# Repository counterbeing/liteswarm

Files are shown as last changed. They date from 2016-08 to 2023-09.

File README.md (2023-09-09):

<p align="center">
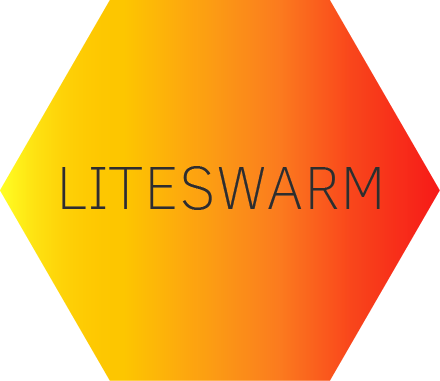
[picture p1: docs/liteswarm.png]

</p>

## 2023-09-08 NOTE
this branch is a merge from a separate repo 100ideas/scarfswarm/releases/tag([BM23](https://github.com/100ideas/scarfswarm/releases/tag/BM23)|[v0.1.0](https://github.com/100ideas/scarfswarm/tree/v0.1.0)) which itself was refactored from [the 2019-july master branch of this  repo counterbeing/liteswarm, somewhere around here](https://github.com/counterbeing/liteswarm/blob/dc4e0e53ea9b77c02f954a00a81d340e21b89678/src/main.cpp). This branch compiles on esp32 dev boards with nrf24 and rotary encoder knobs attached to esp32 GPIO pins as defined in [`/src/config.h`](src/config.h). 

The GPIO pin settings should be compatible with ESP-WROOM-32 DevKit-v1 style breakout boards. I used these "[5PCS ESP-WROOM-32 ESP32 ESP-32S Development Board...](https://www.amazon.com/dp/B0BK13HWBJ) from amazon, but I want to switch to using one of the boards made by [Unexpected Maker](https://unexpectedmaker.com/shop.html) (tbd)."

I forked and old commit of the master branch, back when it was reliably working on arduino teensy in july 2019, and refactored it until it worked on esp32. Note, I have not verified that it STILL works on arduino teensy, so we should add a tag to the old master at a commit that was good on teensy, maybe around here https://github.com/counterbeing/liteswarm/blob/dc4e0e53ea9b77c02f954a00a81d340e21b89678/src/main.cpp. The most recent master commit before my merge from BM23 branch was https://github.com/counterbeing/liteswarm/tree/cc187bc9ed60972e2afc4fb52d72f6577941fd4b.

I started a new repo for my development work, [100ideas/scarfswarm](https://github.com/100ideas/scarfswarm).

## about
continutation of code developed with @counterbeing in https://github.com/counterbeing/liteswarm. `BM23` (and `master` currently) branch here is a minimal refactor of the teensy/arduino-compatible master branch of the liteswarm repo from 2019. Multiple contributors attempted to refactor or rearchitect the liteswarm code for esp32 but I couldn't get any of those branches to run. This branch does run on esp32, but it is not fancy. In fact, the code is ugly. But it works. I will push it to a branch on counterbeing/liteswarm for posterity. This repo is intended to be the home of scarfswarm FOSS firmware and hardware based on esp32, contributed by 100ideas and others.

To compile and upload this code onto an ESP32, use platformio in vscode. Once the platformio extension is activated, it should automagically configure a local gcc toolchain, download the project dependencies (`fastled/FastLED@^3.5.0`, `dparson55/NRFLite@^3.0.3`, `madhephaestus/ESP32Encoder`, `thomasfredericks/Bounce2@^2.55`, and all the magic contained in the `framework = arduino` line of `platformio.ini`), and compile them for esp32. If you encounter trouble building, try disabling `gcc` warnings by using a `platform.ini` similar to below (specifically `build_unflags` line):
```ini
[env:esp32dev]
platform = espressif32
board = esp32dev
framework = espidf
upload_port = /dev/cu.SLAB*
monitor_port = /dev/cu.SLAB_USBtoUART
monitor_speed = 115200
; esp32_exception_decoder is an add-on that parses kernel panic messages on serial such that error codes
;   and memory locations / program counter numbers are replaces with src code coordinates - handy!
monitor_filters = default, esp32_exception_decoder
; fix vendor-default extreme error setting in GCC (example code won't compile)
;   by disabling all gcc warnings
;   https://community.platformio.org/t/disable-warning-errors/13280/3
build_unflags = -Werror=all
; in extreme cases you may need to mess with how the linker/compiler resolves dependencies, try:
; lib_ldf_mode = chain+
```

**END 2023-09-08 NOTE**
---

## Swarming LEDs for LED Fun
This project can be be applied to many projects. Our prototype has been in scarves. These can also go in all sorts of other places:

- Wearables such as scarves and hats.
- Bike safety helmet.
- Bike lights.

### Why these? What's the swarm?
The thing that makes this project unique is the swarm. We're working to establish a way for multiple projects to communicate so that you can sync up animations with friends or even strangers.

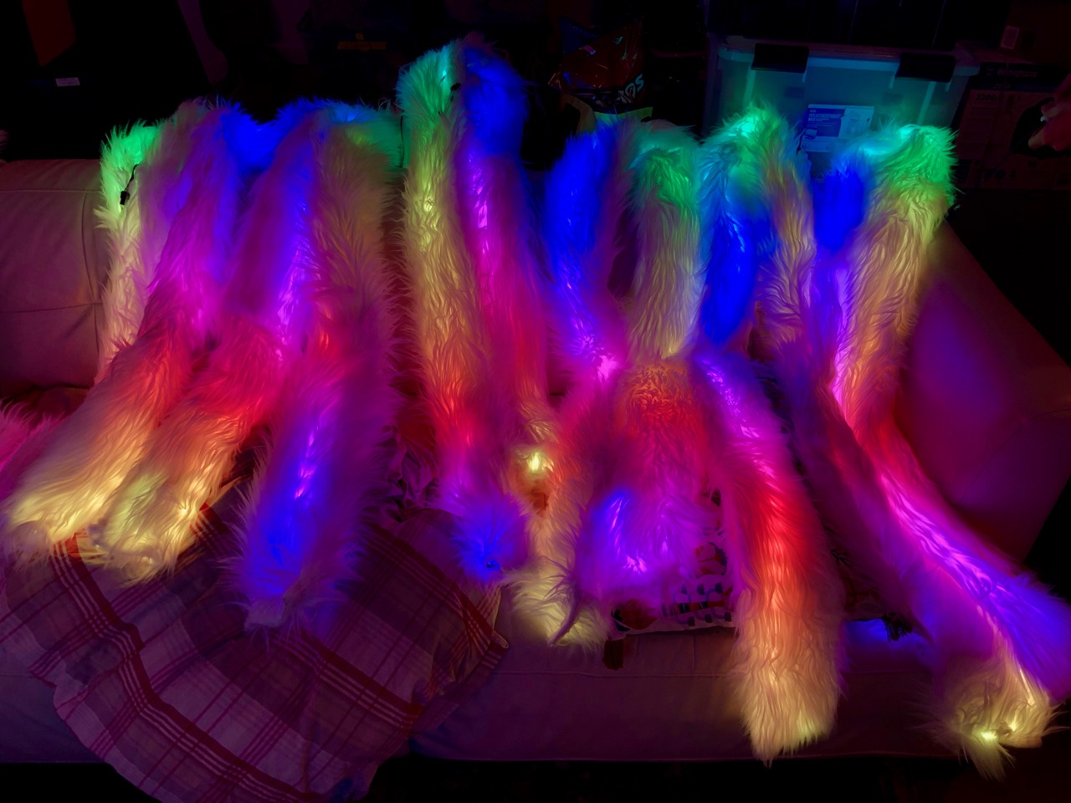
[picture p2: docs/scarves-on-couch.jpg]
Pile of scarves synced up


Cheap simple hardware that can be put together in a robust and ad-hoc way to
keep you safe for nights of partying, or bicycling. Keep your friends all in a group with a synchronized mobile light show.

### Materials / Shopping List
These are some of the materials we've used to build our own. You can pretty much bank on them workin for your project.
- [portable battery packs](https://smile.amazon.com/Smallest-Jackery-3350mAh-Portable-Charger/dp/B00L9F95RO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), not a bad idea to have two. These are small enough to fit inside of a fuzzy scarf, and they don't turn off on you. You can get a few hours out of one of these... Depends on the animation you run. *mac likes Jackery if you can find 6000-12000mAh capacity for less than $20)
- another batt option [PowerAdd Slim 2 5000 mAh Compact Battery Packs](https://www.amazon.com/dp/B00KG45W08) ($13)
- [fabric](https://www.joann.com/luxury-faux-husky-fur-fabric--white/14387674.html)
- [arduino nanos](https://smile.amazon.com/gp/product/B07HF5RMHV/ref=crt_ewc_title_dp_2?ie=UTF8&psc=1&smid=A278BT9THV444Y)
- [led strips](https://www.aliexpress.com/item/5m-5V-WS2812B-WS2812-Led-Strip-light-Individually-Addressable-Smart-RGB-Led-pixel-strips-Black-White/32995915537.html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)
- moar strips [WS2811](https://hackmd.io/@100ideas/scarfswarm#LED-strips) (see hackmd doc below for links to Ray Wu's led store)
- [usb cables](https://www.amazon.com/HTTX-Straight-Soldering-Connector-Replacement/dp/B07D1HDJM8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)
- [rotary encoder](https://smile.amazon.com/DIYhz-Rotary-Encoder-Digital-Potentiometer/dp/B07D3D64X7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)
- [wire](https://www.amazon.com/StrivedayTM-Flexible-Silicone-electronic-electrics/dp/B01KQ2JNLI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)
- [nRF24L01+ 2.4 Ghz radio](http://a.co/d/3rhLgCT)
- Bourns PEC11 12mm 24-pulse rotary encoder (PEC11-4215F-S24) [adafruit #377](https://www.adafruit.com/product/377) ($4.50/1); [datasheet](https://cdn-shop.adafruit.com/datasheets/pec11.pdf) (need 10x)
- [usb type a male adapter 20-pack]( https://www.amazon.com/gp/product/B07GGJGB7Q) ($11) (for making power cables)
- [JST 4pin male-female connector pigtails, pack of 20](https://www.amazon.com/gp/product/B075K3M1TB) ($11)
- [112Pcs 2.54mm Male and Female Pin Header Connector Assortment Kit, 100pcs Stackable Shield Header](https://www.amazon.com/gp/product/B07CWSXY7P) ($13)
- [Capri Tools 20011 Automatic Wire Stripper and Cutter
](https://www.amazon.com/gp/product/B01018CX46) ($14) - get one. changed my life.

scarfwarm-bigred-demo[
Scarfswarm / bikelights Big Red animation demo (youtube 2m)](https://youtu.be/5sAtdrZpyJc)

## Contributing
### Getting Involved
If you'd like to submit a bug, go ahead and use the issue tracker.

If you'd like to make submit a feature or a fix.
  - Open an issue to get buy in.
  - Fork the repo.
  - Make your changes.
  - Submit a pull request.

### Troubleshooting
Things you might be missing.
- edit using VSCode with PlatformIO plugin
- OpenOCD some USB stuff `brew install openocd` (or else `dyld: Library not loaded: /usr/local/opt/libftdi/lib/libftdi1.2.dylib`)

## Reference
**project documentation** https://hackmd.io/@100ideas/scarfswarm

libraries we're using:
- [FastLED.h](https://github.com/FastLED/FastLED) let their be light
- [NRFLite.h](https://github.com/dparson55/NRFLite) ... longwave light
- arduino / teensy [SPI](https://www.pjrc.com/teensy/td_libs_SPI.html) library
- [Encoder](https://github.com/PaulStoffregen/Encoder) - performant quadrature encoder for rotary inputs
- 

---

## 2019-12-12 Teensy-LC + NRF24L01+ notes

teensy forum faq: https://forum.pjrc.com/threads/25395-Teensy-Quick-Reference-Code-Examples-Tips-and-Tricks?highlight=nrf24l01
- also see
  - getting 128-bit ID hardcoded into chip
  - interval timer using interrupts
  - simple task library
  - libs https://www.pjrc.com/teensy/td_libs.html
    - debounce
    - timers

Optimized High Speed NRF24L01+
- https://tmrh20.github.io/RF24/
- mentioned on pjrc forums https://forum.pjrc.com/threads/40499-Need-to-change-SPI-clock-rate-for-RF24-radio-modules-w-TMRh20-library

NRF24L01+ w/ amazon breakout boad diagram
-----------------------------------------------------------------------------------------------

                                                 (pins)       NRF24L01+ breakout board pcb
    | nrf:teensy pin# | nrf:teensy     |      |-----------------------------------------------|
    | --------------- | -------------- |      |[1] | 2  |                      (antenna)      |
    | 1: GND   GND    | 2: VCC  (+3.3v)|      | -- | -- |        -------     ===============  |
    | 3: 9     CE     | 4: 10?  CSN    |      | 3  | 4  |        | C H |        ||   -----||  |
    | 5: 13    SCK    | 6: 11   MOSI   |      | -- | -- |        | I P |        ||   ||-----  |
    | 7: 12    MISO   | 8: ?    IRQ    |      | 5  | 6  |        -------        ||   -----||  |
                                              | -- | -- |                       ||   ||-----  |
                                              | 7  | 8  |                       ||   -----||  |
    Functions as follows:                     |---------|                            ||-----  |
    1: Ground                                 |         ( 16.000 )                        ||  |
    2: Vcc (3.3v)                             |-----------------------------------------------|
    3: CE (Chip Enable)
    4: CSN (Chip Select Not) Active Low - SPI Chip Select function
    5: SCLK (Clock) - SPI Clock Function
    6: MOSI (Master Out Slave In) - SPI Data
    7: MISO (Master In Slave Out) - SPI Data
    8: IRQ (Interrupt) - Optional, but goes low to indicate that data has arrived, fault has
       occurred, or write buffer full.

> SPI has 4 signals: **SS**, **SCK**, **MOSI**, **MISO**. SCK is a clock signal. Master Out Slave In (MOSI) sends data from the SPI master to one or more slaves. Master In Slave Out (MISO) is how slaves send data back to the master. To talk to only one of several slaves, the Slave Select (SS) pin is used. Thus, some chips need only 3 or even 2 of these signals; a display, for example, will use MOSI but not MISO, as it is an output only device.
>
> Multiple SPI devices use the same SPI SCK, MISO and MOSI signals but each device will need it's own SS pin.

| Signal | Function | Teensy 2.0 | Teensy++ 2.0 | Teensy 3+ / LC * | ALT Teensy 3+ / LC |
| --- | --- | --- | --- | --- | --- |
| SS | Select device | 0 | 20 | 10 | - |
| SCK | Clock | 1 | 21 | 13 | 14 |
| MOSI | Data Output | 2 | 22 | 11 | 7 |
| MISO | Data Input | 3 | 23 | 12 | 8 |

\* these pins are set by default by SPI library(?). To use ALT, make calls to `SPI.setMOSI(pin)` etc.

> However, the SS pin must either be configured as an output, or if it is an input, it must remain low during the SPI transfer. Unconfigured pins default to input, and a pin with no signal can easily "float" to random voltages due to electrical noise. Always configure the SS pin as an output, or make sure it remains low.
>
> Sometimes, the SPI pins are already in use for other tasks when an SPI device is added to a project. If that task is simply a digital pin, or an analog input, it is usually better to move that to another pin so that the hardware SPI can be used. Sometimes though, the conflicting pin cannot be moved. The Audio Adapter, for example, uses some of the SPI pins to talk to the Audio DAC over I2S. For this case, Teensy 3.x provides an alternate set of SPI pins.
>
> The main SPI pins are enabled by default. SPI pins can be moved to their alternate position with SPI.setMOSI(pin), SPI.setMISO(pin), and SPI.setSCK(pin). You can move all of them, or just the ones that conflict, as you prefer. The pin must be the actual alternate pin supported by the hardware, see the table above; you can't just assign any random pin.

https://www.pjrc.com/teensy/td_libs_SPI.html

-----------------------------------------------------------------------------------------

## dont overflow if counting packets...
how many packets (max) could a device see per second?
```
(800kbps * 1 second) / 32 bytes = 3125
(2MBps * 1 second) / 32 bytes   = 62500
```
see UINT_MAX from std::numeric_limits 
- https://en.cppreference.com/w/cpp/types/climits
- https://en.cppreference.com/w/cpp/types/integer

| uint sizes | atmel / arduino | teensylc arm cortex M0 |
| --- | --- | --- |
| INT8_MAX | 127 | |
| UINT8_MAX  | 255 | |
| INT16_MAX  | 32767 | |
| UINT16_MAX | 65535 | |
| INT32_MAX  | 2147483647 | |

```c
// https://www.badprog.com/c-type-what-are-uint8-t-uint16-t-uint32-t-and-uint64-t

// testValue
unsigned long long testValue     = 0xFFFFFFFFFFFFFFFF; // 18446744073709551615

// 1 byte -> [0-255] or [0x00-0xFF]
uint8_t         number8     = testValue; // 255
unsigned char    numberChar    = testValue; // 255

// 2 bytes -> [0-65535] or [0x0000-0xFFFF]
uint16_t         number16     = testValue; // 65535
unsigned short    numberShort    = testValue; // 65535

// 4 bytes -> [0-4294967295] or [0x00000000-0xFFFFFFFF]
uint32_t         number32     = testValue; // 4294967295
unsigned int     numberInt    = testValue; // 4294967295

 // 8 bytes -> [0-18446744073709551615] or [0x0000000000000000-0xFFFFFFFFFFFFFFFF]
uint64_t             number64         = testValue; // 18446744073709551615
unsigned long long     numberLongLong    = testValue; // 18446744073709551615
```

## deviceId collisions
calculate liklihook of id collisions, where n = number of devices & d = keyspace size (using birthday problem formula):

1 - (d!) / ((d - n)! * d^n)

n = 10 devices
d = 256 (uint_8)
p = 16%

n = 10 devices
d = 32768 (uint_16)

### 2019-11-21 dev notes for scarfquest
intellisense not picking up uintxx types from `/Users/100ideas/.platformio/packages/toolchain-atmelavr/avr/include/stdint.h`

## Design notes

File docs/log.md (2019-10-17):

## LOG

#### 22 aug 19
- got WS2815s working
- discovered that `NUMLEDS = 375` uses 120% of available memory
  - removing all serial.print statements with static strings saved 406 bytes
  - that was enough space for all animations @ 375 leds
- measured current draw for WS2815 for each animation @ 375 leds (12.5 m)
  - ranges between 0.8-4.25 amps @ 12v
  - so for 25m of strip on big red max power draw ~ 100 watts
  - see comments in `config.h` for details

#### 14 aug 19
- set `"C_Cpp.clang_format_style": "Google",` in `.vscode/settings.json` to get javascriptish formatting rules
- added `include/printf.h`: if included, intercepts output of printf and sends to `serial.print()`. not currently used, but should be.

#### 13 aug 19
- switch push-pattern cmd dispatcher
- FIX pcb v1.3 swapped CS<->CSM pins in `Radio.h`
  ```c
    const static uint8_t PIN_RADIO_CE = 7;  // 7 on PCBs 1.3, was 6 on 1.1
    const static uint8_t PIN_RADIO_CSN = 6; // 6 on PCBs 1.3, was 7 on 1.1
  ```
- determined color channel order for SK9822: BGR

- c experiments
  - https://repl.it/@100ideas/hashmap-vs-switch
  - https://repl.it/@100ideas/knobreducer-binary-sandbox
  - https://repl.it/@100ideas/c-string-and-array-practice
  - https://www.programiz.com/cpp-programming/strings
  - https://en.cppreference.com/w/cpp/language/operator_arithmetic

- buffer rapid presses TODO pseudocode
  ```
  // TODO buffer rapid presses
    } else { ....
      IF rapid presses (where difference < shortPress):
        skip (*_aiIndex)++;
        instead increment rapidPressCount++, once per rapid press
      IF rapid presses over (buttonState == 1 && rapidPressCount > 0)
        (*_aiIndex) += rapidPressCount;
        rapidPressCount == 0;
  ```

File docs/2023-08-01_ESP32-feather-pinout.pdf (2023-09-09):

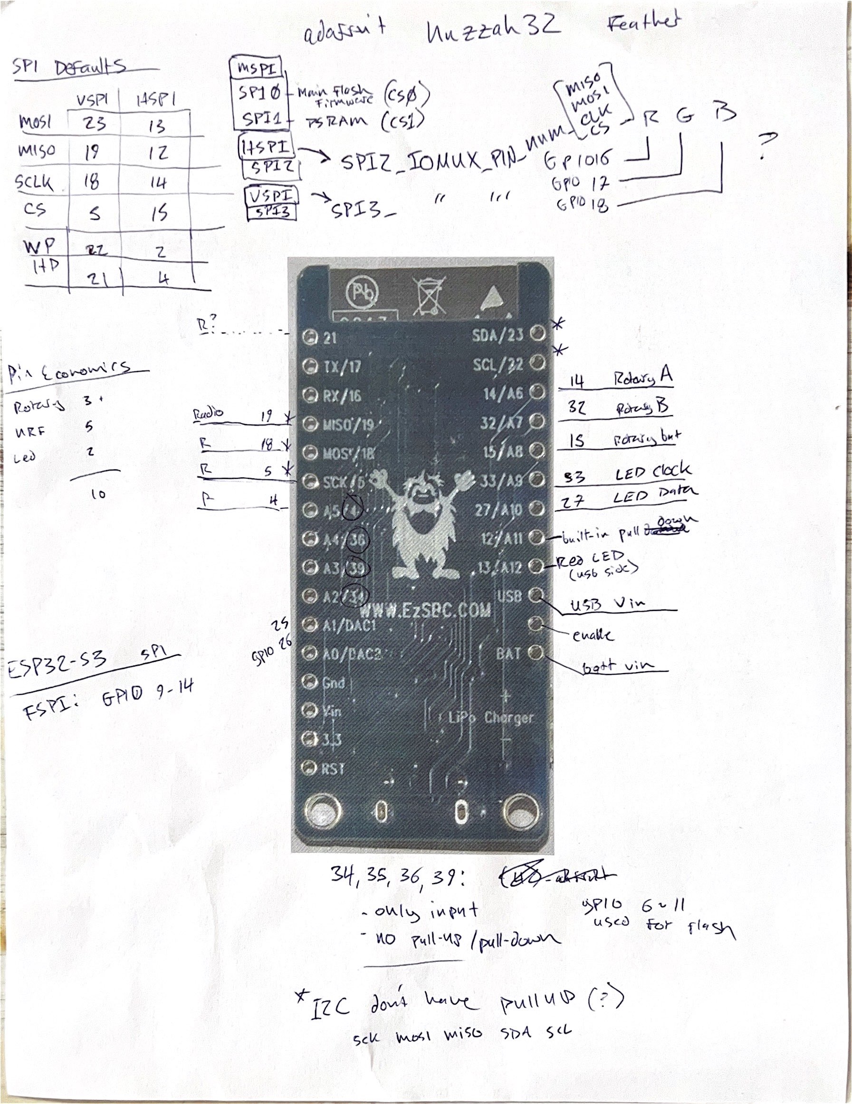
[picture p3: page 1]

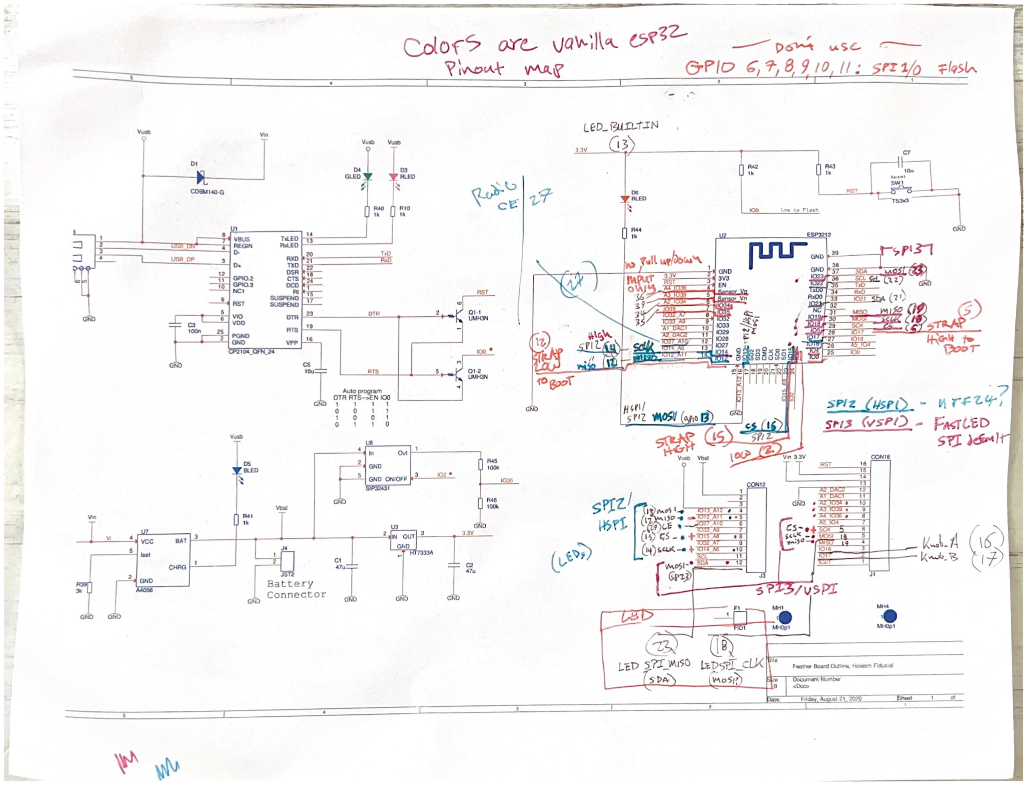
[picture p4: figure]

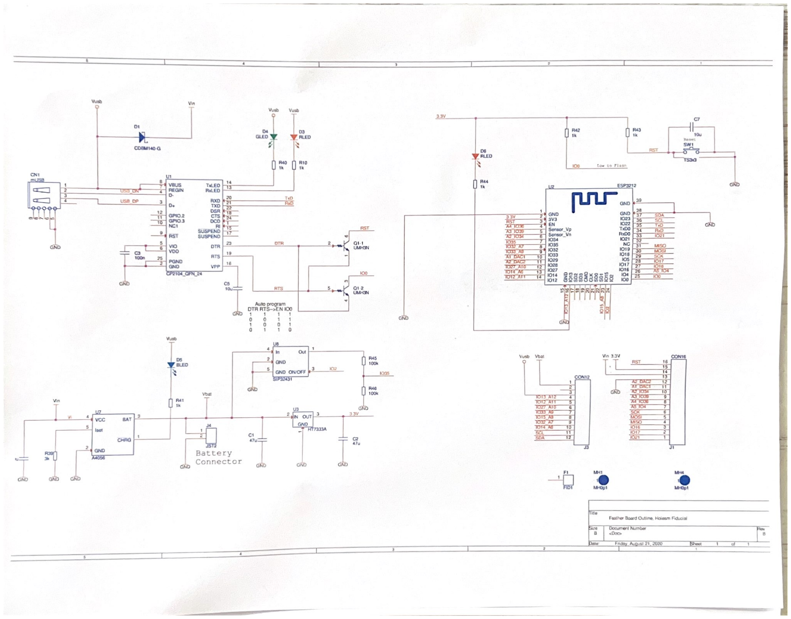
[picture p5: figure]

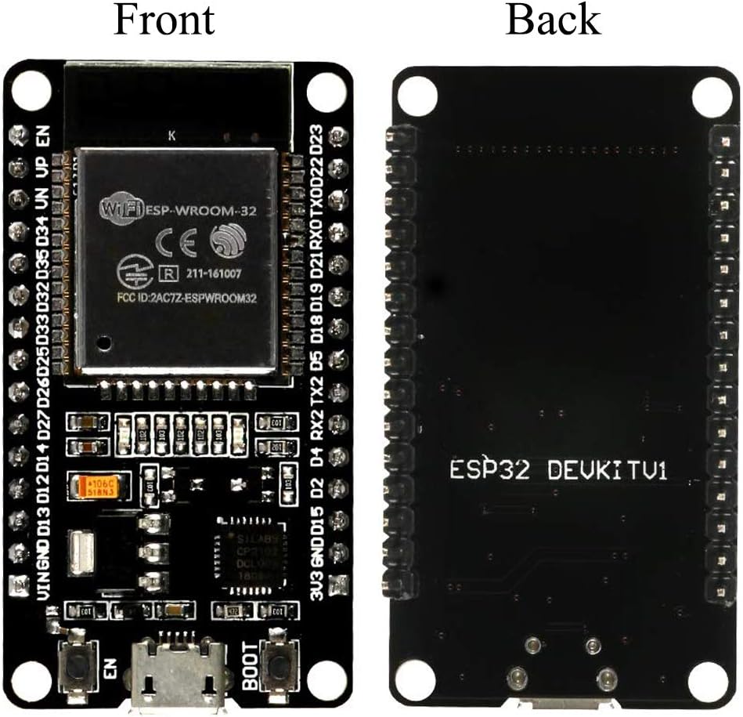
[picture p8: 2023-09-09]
docs/2023-08-01_esp32-devkitv1-amazon_dp_B0BK13HWBJ copy.jpg

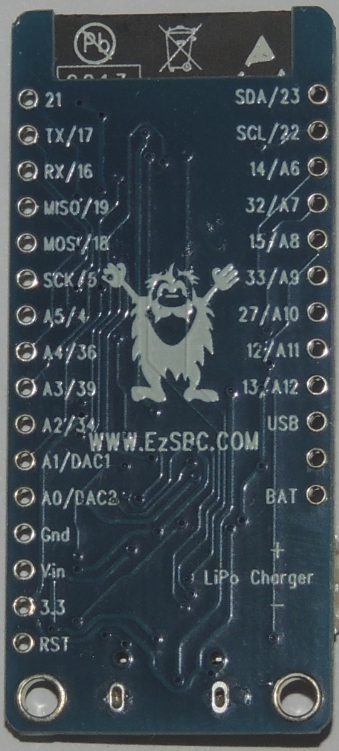
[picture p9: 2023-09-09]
docs/2023-08-01 product_e_s_esp32_feather_back.jpg

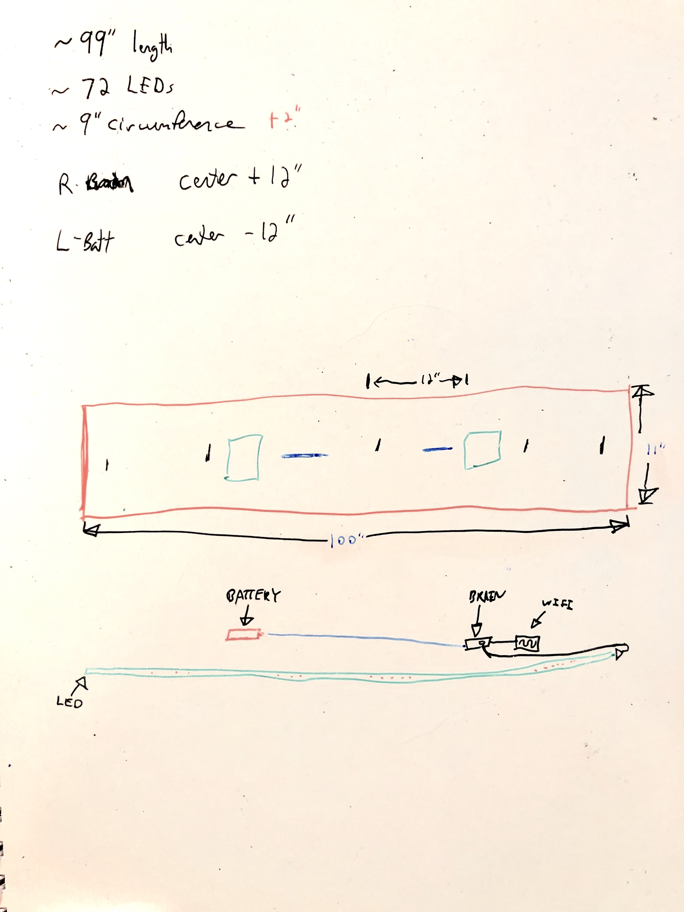
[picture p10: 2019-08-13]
scarf-diagram.jpg

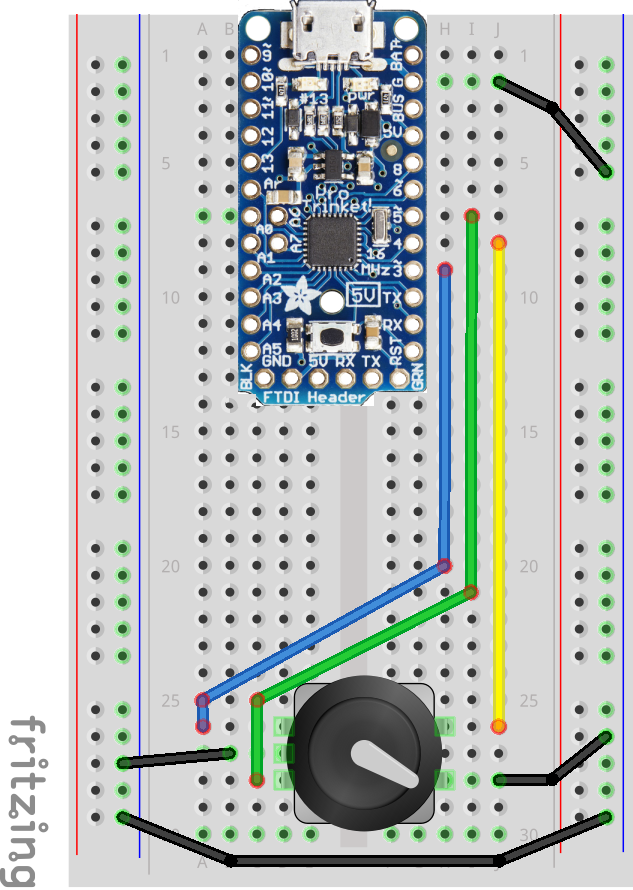
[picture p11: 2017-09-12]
docs/rotary encoder - pro-tinket_Volume_Knob_Fritzing.png

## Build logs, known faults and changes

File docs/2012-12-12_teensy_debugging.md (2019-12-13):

# 2012-12-12 teensy dev & debugging

working on refactoring code from the 'master' branch for teensy_lc.

Hardest part was figuring out the correct pinouts for the radio. 
- `neopixel` style LED strip worked right off the bat
- so did rotary encoder
- radio is hard b/c nrf docs use terms like `csn`, & `ce`, but teensy uses `ss` and doesn't mention the other term as much. See the section in the `readme.md` for an overview.

problem initially presented itself as nrf radio module + NrfLite lib on teensy reporting via terminal that 1) `radio ok`  but 2) logged values for received packets that never changed. As if the packets weren't really getting decoded (although they were being received somehow).

Three theories:

1). wiring is screwed up connecting teensy to nrf, so it isn't able to fully read or correctly decode incoming packets.

2). there is a buffer overflow, typecasting/type mixing mistake in the code. the nrf is working, receiving packets, but decoding them is not; instead we get nonsense or zeor values from random memory locations. I was leaning towards this explanation because I found a ton of mixed types (uint8_t -> int; long -> int, etc). But after standardizing a bunch of them, still got communication problems.

3). the teensy has a much faster clock (100mhz?) than the arduino. According to the official documentation and forum/issue posts on nrflite repo, the crystal resonator in the nrf24l01 that generates the radio frequencies is unable to work effectively above some frequency range... perhaps 8khz at the high end? [Here is an issue on nrflite recommending limiting clock speed to 4khz](https://github.com/dparson55/NRFLite/issues/19). But based on reading the issue, it doesn't sound particularly straightforward to force the arduino + nrf libs running on the teensy to step down to 4khz. Gonna play with this next. [also a forum post on teensy forums](https://forum.pjrc.com/threads/40499-Need-to-change-SPI-clock-rate-for-RF24-radio-modules-w-TMRh20-library).

4). well one last theory: I skimmed the commit log for the master branch (counterbeing/bikelights) and didn't see anything too alarming, so thats what I adapted. But its totally possible it has subtle work-in-progress bits that are tripping up the logic of the current program. I've gone over everything a multiple times but nothing is obviously screwed up... could you guys have a look?

### changes on this branch
- added more preporcessor / compiler directives to config.h to simplofy switching between developing for nano vs teensy
- added teensy config to `platformio.ini`. this should make two `"env"` (board)-dependant sections appear in the platformio "project tasks" sidebar, one for nano, and one for teensy. Just plug whichever board in and click the appropriate build/compile/monitor - it figures it out on its own.
- standardized data types used to pack & upack the radio packet.

### symptoms
see console log below. its the serial output of a nano running on my desk right next to the teensy. its getting the correct 'shared_secret', and 'animationId' increments on the receiver if I spem the rotary over and over, but the system almost immediately races away from user input towards some minima or maxima; in particular, neither unit successfully synchronizes towards shared state with the other one, at least with the 'rotaryPosition' parameter. The other params seem to be more stable.

So I think whats happening is a bad logic around [line 90 of Radio.h](https://). The `stateChanged()` method always sees a different local rotaryPosition than the one in the incoming packet, so it spams updates at the other device, the recipient spams back, and both get locked in an unstable positive feedback loop.  (*note: maybe we should add a naieve 'back-off' algorithm to the radios to keep the packet density from spiraling out of control like this - that, and adding CRC / checksum code...)

**anyway, I can't figure out why currentRotary** isn't getting set correctly from the incoming packets. Am I trying to compare the literal value of the pointer to the local currentRotary with the proper value of the incoming packet (fail), or is the memory space of the struct in which the packet is stored is getting overriden (yes? can't tell), or is it unintended behavior from the interplay of code that sets the `rotaryPosition` after it changes (due to incoming packet or user input) and the code the animations call (` `MyKnob.h` line 442: confine()`) to scale and loop the rotary values over a particular range?

Well, I've tried a bunch of little experiments and came up with nada. I finished 2/3rds of the pcb of the teensy yesterday and I need to finish it and submit it soon to have a chance at getting it fabbed for xmas. I would love to have fully validated the software side before comitting to particular pins on the teensy but I'm stuck - can you help?  Tell me if I'm using an out of date branch (gaaaahhh), or perhaps you'll see the data type error if there is one, or merge my config.h changes into your/Tony's remastered branch.

---

see how `rotaryPosition` changes (or doesn't) in response to me playing with the knob on either the teensy (remote) or nano (logged to serial).

some interesting values:

`rotaryPosition`:

| incoming value | local value |
| --- | --- |
| `-939524096` | `5` |
| `0` | `5` |
| ...later | ... |
| '0' | '255' |

- senderId sometimes shows the correct value
- shared secret was `0` for a long time. not sure how I fixed it.

## control test
testing this codebase with two vanilla nano scarves, both neopixel

#### test 1: 
- nano_a has code from this branch (teensy) with latest commit
- nano_b has whatever code I put on it over thanksgiving. (it was working then).
-  rotary on nano_b 
  - clicking: nano_b flashes quickly - probably switching to new animation then instantly switching back. won't stay switched. similar to teensy.
  - twisting - unsure if this does anything
  - nothing shows up in serial
  - nothing appears to happen to nano_a
-  rotary on nano_a:
  - clicking: switched to next animation for approx 1 sec, then back. no effect on nano_a. fast clicking can advance through several animations
  - twisting: seems to modulate animation as expected

#### test 2: 
- nano_a & nano_b have code from this branch (teensy) with latest commit
- **AW FUCK** both scarves perform more or less as expected. no crazy values, no runaway feedback loops....
- **so its probably not code... but bad wiring or the clock rate on the teensy**.

## new theory: compiler pads memory space of packet struct differently on nano (8-bit) vs teensy (32-bit)

I think this is what's going on! will test soon.

apparently the c compiler tries optimize the memory layout of *struct*ure members according to constraints / rules that partially depend on system architecture (word size?). If the struct's members are of different sizes, the compiler may elect to pad the smaller ones such that the whole struct lays out more regularly in memory.

Our code currently packs 4 numbers into a 48-byte `struct` that is passed to the radio for transmission, or conversely received and unpacked.

The preferred memory layout of the stuct in memory space is probably different on teensy vs nano - thus leading to what appear to be buffer overrun type bugs when one platform gets a packet with that was packed and padded for a different architecture.

apparently the `#pragma pack(n)` compiler directive can control the compilers packing strategy, where n = how many padding bytes can be added around each member to make the struct's overall memory footprint "square". `n = 1` should make it nice and "1-dimensional" and resolve the problem if we're lucky (hopefully its not more complicated than this).

**thanks be to @SadatD for the following explaination, originally posted to https://stackoverflow.com/questions/3318410/pragma-pack-effect#3318475**: 

>  `#pragma pack` instructs the compiler to pack structure members with particular alignment.  >  Most compilers, when you declare a struct, will insert padding between members to ensure that they are aligned to appropriate addresses in memory (usually a multiple of the type's size).  This avoids the performance penalty (or outright error) on some architectures associated with accessing variables that are not aligned properly.  For example, given 4-byte integers and the following struct:
>
>      struct Test
>      {
>         char AA;
>         int BB;
>         char CC;
>      };
>  
>  The compiler could choose to lay the struct out in memory like this:
>  
>      |   1   |   2   |   3   |   4   |  
>  
>      | AA(1) | pad.................. |
>      | BB(1) | BB(2) | BB(3) | BB(4) | 
>      | CC(1) | pad.................. |
>  
>  and `sizeof(Test)` would be 4 &times; 3 = 12, even though it only contains 6 bytes of data.  >  The most common use case for the `#pragma` (to my knowledge) is when working with hardware devices where you need to ensure that the compiler does not insert padding into the data and each member follows the previous one.  With `#pragma pack(1)`, the struct above would be laid out like this:
>
>      |   1   |
>  
>      | AA(1) |
>      | BB(1) |
>      | BB(2) |
>      | BB(3) |
>      | BB(4) |
>      | CC(1) |
>  
>  
>  
>  And `sizeof(Test)` would be 1 &times; 6 = 6.
>  
>  With `#pragma pack(2)`, the struct above would be laid out like this:
>  
>      |   1   |   2   | 
>  
>      | AA(1) | pad.. |
>      | BB(1) | BB(2) |
>      | BB(3) | BB(4) |
>      | CC(1) | pad.. |
>  
>  And `sizeof(Test)` would be 2 &times; 4 =  8.
>  
>  Order of variables in struct is also important. With variables ordered like following:
>  
>      struct Test
>      {
>         char AA;
>         char CC;
>         int BB;
>      };
>  
>  and with `#pragma pack(2)`, the struct would be laid out like this:
>  
>  
>      |   1   |   2   | 
>  
>      | AA(1) | CC(1) |
>      | BB(1) | BB(2) |
>      | BB(3) | BB(4) |
>  
>  and `sizeOf(Test)` would be 3 × 2 = 6.
>   .

references:
- https://forum.pjrc.com/threads/24940-Teensy-3-1-nrf24l01-issue
- https://docs.microsoft.com/en-us/cpp/preprocessor/pack?view=vs-2019

can't wait

---

### nano communicating with teensy v2 (teensy branch latest)
``` log
> Executing task: platformio run --target upload --target monitor --environment nano <

Processing nano (platform: atmelavr; board: nanoatmega328new; framework: arduino)
--------------------------------------------------------------------------------------------------
Verbose mode can be enabled via `-v, --verbose` option
CONFIGURATION: https://docs.platformio.org/page/boards/atmelavr/nanoatmega328new.html
PLATFORM: Atmel AVR 2.0.0 > Arduino Nano ATmega328 (New Bootloader)
HARDWARE: ATMEGA328P 16MHz, 2KB RAM, 30KB Flash
PACKAGES: toolchain-atmelavr 1.50400.190710 (5.4.0), framework-arduino-avr 5.0.0, tool-avrdude 1.60300.190628 (6.3.0)
LDF: Library Dependency Finder -> http://bit.ly/configure-pio-ldf
LDF Modes: Finder ~ chain, Compatibility ~ soft
Found 11 compatible libraries
Scanning dependencies...
Dependency Graph
|-- <FastLED> 3.3.2
|   |-- <SPI> 1.0
|   |-- <SoftwareSerial> 1.0
|-- <Bounce2> 2.52
|-- <Encoder> #4c4ec3a
|-- <SPI> 1.0
|-- <NRFLite> 2.2.2
|   |-- <SPI> 1.0
Building in release mode
Checking size .pio/build/nano/firmware.elf
Advanced Memory Usage is available via "PlatformIO Home > Project Inspect"
DATA:    [=======   ]  68.9% (used 1412 bytes from 2048 bytes)
PROGRAM: [=====     ]  46.6% (used 14306 bytes from 30720 bytes)
Configuring upload protocol...
AVAILABLE: arduino
CURRENT: upload_protocol = arduino
Looking for upload port...
Auto-detected: /dev/cu.usbserial-1460
Uploading .pio/build/nano/firmware.hex

avrdude: AVR device initialized and ready to accept instructions

Reading | ################################################## | 100% 0.00s

avrdude: Device signature = 0x1e950f (probably m328p)
avrdude: reading input file ".pio/build/nano/firmware.hex"
avrdude: writing flash (14306 bytes):

Writing | ################################################## | 100% 2.51s

avrdude: 14306 bytes of flash written
avrdude: verifying flash memory against .pio/build/nano/firmware.hex:
avrdude: load data flash data from input file .pio/build/nano/firmware.hex:
avrdude: input file .pio/build/nano/firmware.hex contains 14306 bytes
avrdude: reading on-chip flash data:

Reading | ################################################## | 100% 1.87s

avrdude: verifying ...
avrdude: 14306 bytes of flash verified

avrdude: safemode: Fuses OK (E:00, H:00, L:00)

avrdude done.  Thank you.

================================== [SUCCESS] Took 6.97 seconds ==================================
--- Miniterm on /dev/cu.usbserial-1460  115200,8,N,1 ---
--- Quit: Ctrl+C | Menu: Ctrl+T | Help: Ctrl+T followed by Ctrl+H ---
0Picking random radio id: 17831
------CE & CSN---------
PIN_RADIO_CE (chip enable): 7
PIN_RADIO_CSN (chip select / slave select)?: 6
radio ok
------INCOMING---------
SHARED_SECRET: 42
rotaryPosition: -939524096
         (local rotaryPosition: 40)
animationId: 0  (local animationId: 0)
senderId: 0
------INCOMING---------
SHARED_SECRET: 42
rotaryPosition: -939524096
         (local rotaryPosition: 5)
animationId: 0  (local animationId: 0)
senderId: 0
--- Sending Data
------INCOMING---------
SHARED_SECRET: 42
rotaryPosition: 0
         (local rotaryPosition: 5)
animationId: 0  (local animationId: 0)
senderId: 0
--- Sending Data
------INCOMING---------
SHARED_SECRET: 42
rotaryPosition: 0
         (local rotaryPosition: 5)
animationId: 0  (local animationId: 0)
senderId: 0
--- Sending Data
------INCOMING---------
SHARED_SECRET: 42
rotaryPosition: 0
         (local rotaryPosition: 5)
animationId: 0  (local animationId: 0)
senderId: 0
--- Sending Data
------INCOMING---------
SHARED_SECRET: 42
rotaryPosition: 0
         (local rotaryPosition: 5)
animationId: 0  (local animationId: 0)
senderId: 0
--- Sending Data
------INCOMING---------
SHARED_SECRET: 42
rotaryPosition: 0
         (local rotaryPosition: 5)
animationId: 0  (local animationId: 0)
senderId: 0
--- Sending Data
------INCOMING---------
SHARED_SECRET: 42
rotaryPosition: 0
         (local rotaryPosition: 5)
animationId: 0  (local animationId: 0)
senderId: 0
--- Sending Data
------INCOMING---------
SHARED_SECRET: 42
rotaryPosition: 0
         (local rotaryPosition: 5)
animationId: 0  (local animationId: 0)
senderId: 0
--- Sending Data
------INCOMING---------
SHARED_SECRET: 42
rotaryPosition: 0
         (local rotaryPosition: 5)
animationId: 0  (local animationId: 0)
senderId: 0
--- Sending Data
------INCOMING---------
SHARED_SECRET: 42
rotaryPosition: 0
         (local rotaryPosition: 5)
animationId: 0  (local animationId: 0)
senderId: 0
--- Sending Data
------INCOMING---------
SHARED_SECRET: 42
rotaryPosition: 0
         (local rotaryPosition: 5)
animationId: 0  (local animationId: 0)
senderId: 0
--- Sending Data
------INCOMING---------
SHARED_SECRET: 42
rotaryPosition: 0
         (local rotaryPosition: 5)
animationId: 0  (local animationId: 0)
senderId: 0
--- Sending Data
------INCOMING---------
SHARED_SECRET: 42
rotaryPosition: 0
         (local rotaryPosition: 5)
animationId: 0  (local animationId: 0)
senderId: 0
--- Sending Data
------INCOMING---------
SHARED_SECRET: 42
rotaryPosition: 0
         (local rotaryPosition: 5)
animationId: 0  (local animationId: 0)
senderId: 0
--- Sending Data
------INCOMING---------
SHARED_SECRET: 42
rotaryPosition: 0
         (local rotaryPosition: 5)
animationId: 0  (local animationId: 0)
senderId: 0
--- Sending Data
------INCOMING---------
SHARED_SECRET: 42
rotaryPosition: 0
         (local rotaryPosition: 5)
animationId: 0  (local animationId: 0)
senderId: 0
--- Sending Data
------INCOMING---------
SHARED_SECRET: 42
rotaryPosition: 0
         (local rotaryPosition: 5)
animationId: 0  (local animationId: 0)
senderId: 0
--- Sending Data
------INCOMING---------
SHARED_SECRET: 42
rotaryPosition: 0
         (local rotaryPosition: 5)
animationId: 0  (local animationId: 0)
senderId: 0
--- Sending Data
------INCOMING---------
SHARED_SECRET: 42
rotaryPosition: 0
         (local rotaryPosition: 5)
animationId: 0  (local animationId: 0)
senderId: 0
--- Sending Data
------INCOMING---------
SHARED_SECRET: 42
rotaryPosition: 0
         (local rotaryPosition: 5)
animationId: 0  (local animationId: 0)
senderId: 0
--- Sending Data
------INCOMING---------
SHARED_SECRET: 42
rotaryPosition: 0
         (local rotaryPosition: 5)
animationId: 0  (local animationId: 0)
senderId: 0
--- Sending Data
------INCOMING---------
SHARED_SECRET: 42
rotaryPosition: 0
         (local rotaryPosition: 5)
animationId: 0  (local animationId: 0)
senderId: 0
--- Sending Data
------INCOMING---------
SHARED_SECRET: 42
rotaryPosition: 0
         (local rotaryPosition: 5)
animationId: 0  (local animationId: 0)
senderId: 0
--- Sending Data
------INCOMING---------
SHARED_SECRET: 42
rotaryPosition: 0
         (local rotaryPosition: 5)
animationId: 0  (local animationId: 0)
senderId: 0
--- Sending Data
------INCOMING---------
SHARED_SECRET: 42
rotaryPosition: 0
         (local rotaryPosition: 5)
animationId: 0  (local animationId: 0)
senderId: 0
--- Sending Data
------INCOMING---------
SHARED_SECRET: 42
rotaryPosition: 0
         (local rotaryPosition: 5)
animationId: 0  (local animationId: 0)
senderId: 0
--- Sending Data
------INCOMING---------
SHARED_SECRET: 42
rotaryPosition: 0
         (local rotaryPosition: 5)
animationId: 0  (local animationId: 0)
senderId: 0
--- Sending Data
------INCOMING---------
SHARED_SECRET: 42
rotaryPosition: 0
         (local rotaryPosition: 5)
animationId: 0  (local animationId: 0)
senderId: 0
--- Sending Data
------INCOMING---------
SHARED_SECRET: 42
rotaryPosition: 0
         (local rotaryPosition: 5)
animationId: 0  (local animationId: 0)
senderId: 0
--- Sending Data
------INCOMING---------
SHARED_SECRET: 42
rotaryPosition: 0
         (local rotaryPosition: 5)
animationId: 0  (local animationId: 0)
senderId: 0
--- Sending Data
------INCOMING---------
SHARED_SECRET: 42
rotaryPosition: 0
         (local rotaryPosition: 5)
animationId: 0  (local animationId: 0)
senderId: 0
--- Sending Data
------INCOMING---------
SHARED_SECRET: 42
rotaryPosition: 0
         (local rotaryPosition: 5)
animationId: 0  (local animationId: 0)
senderId: 0
--- Sending Data
------INCOMING---------
SHARED_SECRET: 42
rotaryPosition: 0
         (local rotaryPosition: 5)
animationId: 0  (local animationId: 0)
senderId: 0
--- Sending Data
------INCOMING---------
SHARED_SECRET: 42
rotaryPosition: 0
         (local rotaryPosition: 5)
animationId: 0  (local animationId: 0)
senderId: 0
--- Sending Data
------INCOMING---------
SHARED_SECRET: 42
rotaryPosition: 0
         (local rotaryPosition: 5)
animationId: 0  (local animationId: 0)
senderId: 0
--- Sending Data
------INCOMING---------
SHARED_SECRET: 42
rotaryPosition: 0
         (local rotaryPosition: 5)
animationId: 0  (local animationId: 0)
senderId: 0
--- Sending Data
------INCOMING---------
SHARED_SECRET: 42
rotaryPosition: 0
         (local rotaryPosition: 5)
animationId: 0  (local animationId: 0)
senderId: 0
--- Sending Data
------INCOMING---------
SHARED_SECRET: 42
rotaryPosition: 0
         (local rotaryPosition: 5)
animationId: 0  (local animationId: 0)
senderId: 0
--- Sending Data
------INCOMING---------
SHARED_SECRET: 42
rotaryPosition: 0
         (local rotaryPosition: 5)
animationId: 0  (local animationId: 0)
senderId: 0
--- Sending Data
------INCOMING---------
SHARED_SECRET: 42
rotaryPosition: 0
         (local rotaryPosition: 5)
animationId: 0  (local animationId: 0)
senderId: 0
--- Sending Data
------INCOMING---------
SHARED_SECRET: 42
rotaryPosition: 0
         (local rotaryPosition: 5)
animationId: 0  (local animationId: 0)
senderId: 0
--- Sending Data
------INCOMING---------
SHARED_SECRET: 42
rotaryPosition: 0
         (local rotaryPosition: 5)
animationId: 0  (local animationId: 0)
senderId: 0
--- Sending Data
------INCOMING---------
SHARED_SECRET: 42
rotaryPosition: 0
         (local rotaryPosition: 5)
animationId: 0  (local animationId: 0)
senderId: 0
--- Sending Data
------INCOMING---------
SHARED_SECRET: 42
rotaryPosition: 0
         (local rotaryPosition: 5)
animationId: 0  (local animationId: 0)
senderId: 0
--- Sending Data
------INCOMING---------
SHARED_SECRET: 42
rotaryPosition: 0
         (local rotaryPosition: 5)
animationId: 0  (local animationId: 0)
senderId: 0

--- exit ---

Environment    Status    Duration
-------------  --------  ------------
nano           SUCCESS   00:00:06.972
teensy         IGNORED
================================== 1 succeeded in 00:00:06.972 ==================================

Terminal will be reused by tasks, press any key to close it.
```

### nano communicating with teensy part 2 (teensy branch latest)
```log
 0
--- Sending Data
------INCOMING---------
SHARED_SECRET: 42
rotaryPosition: 0
         (local rotaryPosition: 255)
animationId: 4  (local animationId: 4)
senderId: 0
--- Sending Data
------INCOMING---------
SHARED_SECRET: 42
rotaryPosition: 0
         (local rotaryPosition: 255)
animationId: 4  (local animationId: 4)
senderId: 0
--- Sending Data
------INCOMING---------
SHARED_SECRET: 42
rotaryPosition: 0
         (local rotaryPosition: 255)
animationId: 4  (local animationId: 4)
senderId: 0
--- Sending Data
------INCOMING---------
SHARED_SECRET: 42
rotaryPosition: 0
         (local rotaryPosition: 255)
animationId: 4  (local animationId: 4)
senderId: 0
--- Sending Data
------INCOMING---------
SHARED_SECRET: 42
rotaryPosition: 0
         (local rotaryPosition: 255)
animationId: 4  (local animationId: 4)
senderId: 0
--- Sending Data
------INCOMING---------
SHARED_SECRET: 42
rotaryPosition: 0
         (local rotaryPosition: 255)
animationId: 4  (local animationId: 4)
senderId: 0
--- Sending Data
------INCOMING---------
SHARED_SECRET: 42
rotaryPosition: 0
         (local rotaryPosition: 255)
animationId: 4  (local animationId: 4)
senderId: 0
--- Sending Data
------INCOMING---------
SHARED_SECRET: 42
rotaryPosition: 0
         (local rotaryPosition: 255)
animationId: 4  (local animationId: 4)
senderId: 0
--- Sending Data
------INCOMING---------
SHARED_SECRET: 42
rotaryPosition: 0
         (local rotaryPosition: 255)
animationId: 4  (local animationId: 4)
senderId: 0
--- Sending Data
------INCOMING---------
SHARED_SECRET: 42
rotaryPosition: 0
         (local rotaryPosition: 255)
animationId: 4  (local animationId: 4)
senderId: 0
--- Sending Data
------INCOMING---------
SHARED_SECRET: 42
rotaryPosition: 0
         (local rotaryPosition: 255)
animationId: 4  (local animationId: 4)
senderId: 0
--- Sending Data
------INCOMING---------
SHARED_SECRET: 42
rotaryPosition: 0
         (local rotaryPosition: 255)
animationId: 4  (local animationId: 4)
senderId: 0
--- Sending Data
------INCOMING---------
SHARED_SECRET: 42
rotaryPosition: 0
         (local rotaryPosition: 255)
animationId: 4  (local animationId: 4)
senderId: 0
--- Sending Data
------INCOMING---------
SHARED_SECRET: 42
rotaryPosition: 0
         (local rotaryPosition: 255)
animationId: 4  (local animationId: 4)
senderId: 0
--- Sending Data
------INCOMING---------
SHARED_SECRET: 42
rotaryPosition: 0
         (local rotaryPosition: 255)
animationId: 4  (local animationId: 4)
senderId: 0
--- Sending Data
------INCOMING---------
SHARED_SECRET: 42
rotaryPosition: 0
         (local rotaryPosition: 255)
animationId: 4  (local animationId: 4)
senderId: 0
--- Sending Data
------INCOMING---------
SHARED_SECRET: 42
rotaryPosition: 0
```

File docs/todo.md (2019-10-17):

## SOFTWARE TODO

#### last updated 22 aug 18
  - [ ] add visual feedback (use amimationCombinator w/ strobe)
  - [ ] buffer rapid presses?
  - [ ] debug flag that enables the above and sets `NUMLEDS` to ~10 (trade leds  for serial print strings in memory)
  - [ ] save memory by casting `long`s to something else (`uint_16`?) i.e. in MyKnob.h
  - [x] Ensure radio is muted for first second or so of operation. This will ensure that a newly booted radio doesn't alter the group's animation sequence.
  - [x] Ensure that non-matching packet secrets ignore packet.
  - [x] `config.h` `KNOB_DEBUG` & `RADIO_DEBUG` enable/disable serial print lines
  - [x] add `ifdefs` to `config.h` to set options for ws2811, ws2815, sk9822
  - [x] lowpower mode triggered by 3000 ms long press
  - [x] swap order of cmdMode pattern from short-med to med-short
  - [x] wrap press duration logic in descriptive variables

## PCB TODO

#### last updated 22 aug 18
  - [ ] switch 6/7 labels on silkscreen
  - [ ] switch clock & data on silkscreen
  - [ ] move position of version label on silkscreen so visible after wires added
  - [ ] increase inside diameter of power holes, radio holes
  - [ ] add holes to the corners, esp opposite radio end; use ziptie thru holes to secure cables
  - [ ] switch radio pins layout from 1x7 to 2x8 compatibile with female ribbon cable header (we'll just solder 2 rows of 1x4 header pins to those holes then push the ribbon cable on)

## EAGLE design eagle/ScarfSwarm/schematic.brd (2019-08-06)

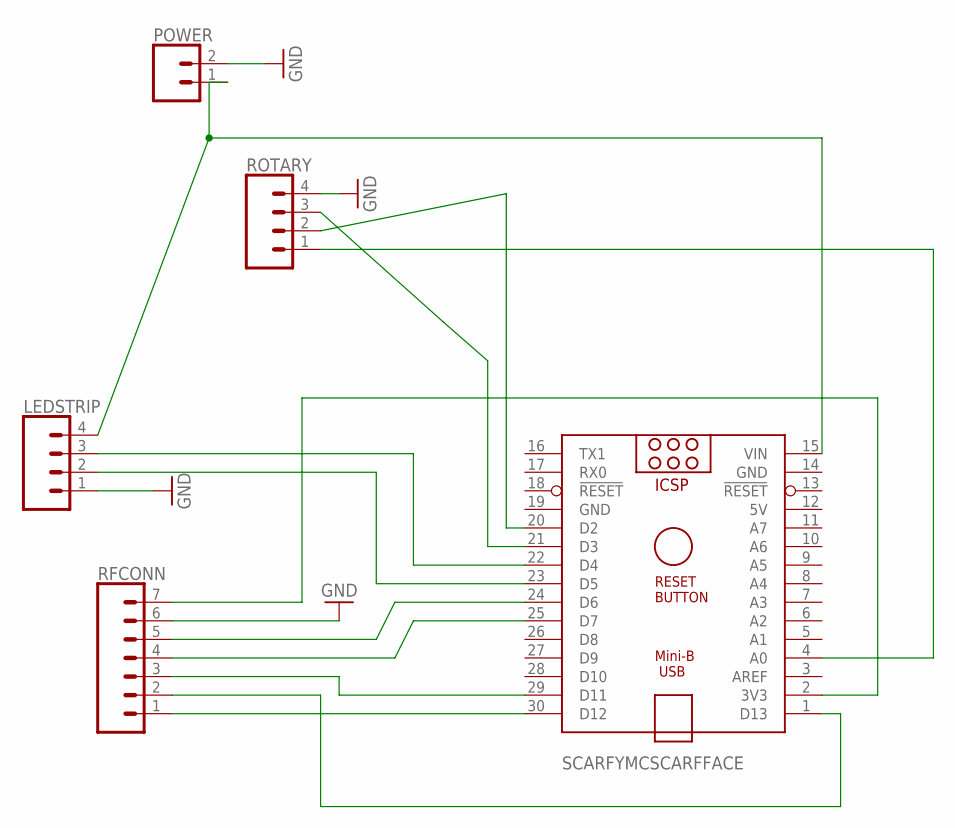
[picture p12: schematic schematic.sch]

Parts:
LEDSTRIP: CONN_04PTH; 1X04
POWER: CONN_02LOCK_LONGPADS; 1X02_LOCK_LONGPADS
RFCONN: CONN_07; 1X07
ROTARY: CONN_04PTH; 1X04
SCARFYMCSCARFFACE: ARDUINO_NANO

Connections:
5V: SCARFYMCSCARFFACE.12 (5V)
GND: LEDSTRIP.1, POWER.2, RFCONN.6, ROTARY.4, SCARFYMCSCARFFACE.14 (GND), SCARFYMCSCARFFACE.19 (GND)
unnamed: RFCONN.7, SCARFYMCSCARFFACE.2 (3V3)
unnamed: RFCONN.5, SCARFYMCSCARFFACE.24 (D6)
unnamed: RFCONN.4, SCARFYMCSCARFFACE.25 (D7)
unnamed: RFCONN.2, SCARFYMCSCARFFACE.1 (D13)
unnamed: RFCONN.3, SCARFYMCSCARFFACE.29 (D11)
unnamed: RFCONN.1, SCARFYMCSCARFFACE.30 (D12)
unnamed: LEDSTRIP.2, SCARFYMCSCARFFACE.23 (D5)
unnamed: ROTARY.3, SCARFYMCSCARFFACE.21 (D3)
unnamed: ROTARY.2, SCARFYMCSCARFFACE.20 (D2)
unnamed: ROTARY.1, SCARFYMCSCARFFACE.4 (A0)
unnamed: LEDSTRIP.4, POWER.1, SCARFYMCSCARFFACE.15 (VIN)
unnamed: LEDSTRIP.3, SCARFYMCSCARFFACE.22 (D4)

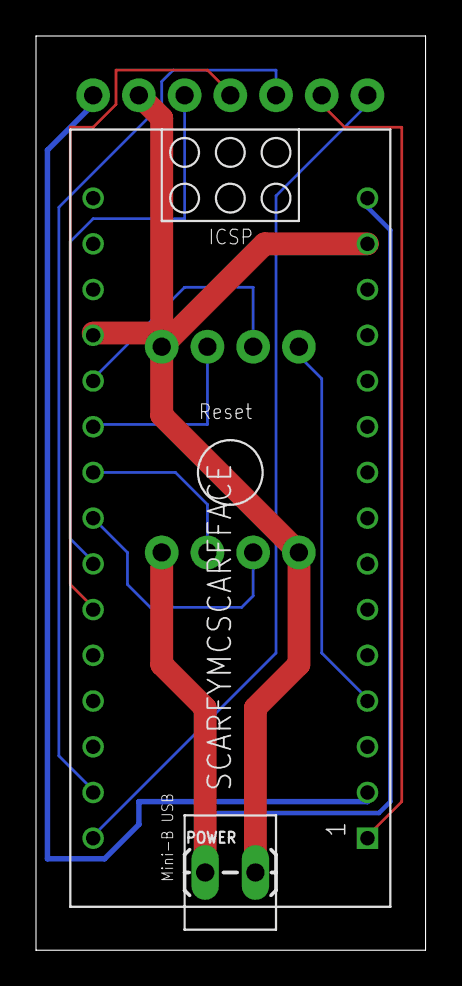
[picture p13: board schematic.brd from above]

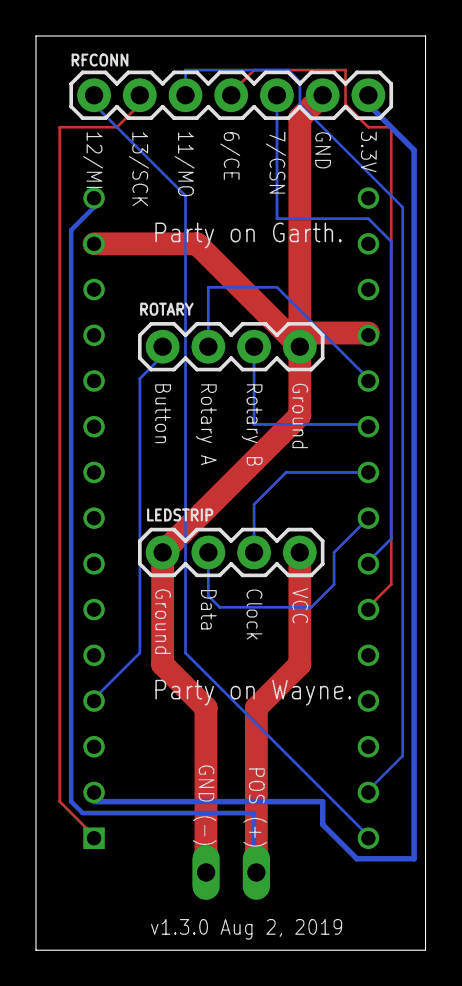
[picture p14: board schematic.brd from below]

Board: 2 copper layers, 21.6 x 50.8 mm, 5 parts (3 on the bottom side), 13 nets.

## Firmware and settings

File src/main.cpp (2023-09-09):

#include "config.h"
#include "SPI.h"
#include <Arduino.h>
#include <NRFLite.h>
// #include <ESP32Encoder.h>
// #include <Bounce2.h>
#include "MyKnob.h"

MyKnob knob;

// this version is port of the early ledswarm 2019 code
// https://github.com/counterbeing/liteswarm/blob/dc4e0e53ea9b77c02f954a00a81d340e21b89678/src/main.cpp

///////////////////////////////////////////////////////////////////////////////////////////
// init FastLED
/* FastLED ESP32 Hardware SPI Driver
 * https://github.com/FastLED/FastLED/blob/master/src/platforms/esp/32/fastspi_esp32.h
 *
 * This hardware SPI implementation can drive clocked LEDs from either the
 * VSPI or HSPI bus (aka SPI2 & SPI3). No support is provided for SPI1, because it is 
 * shared among devices and the cache for data (code) in the Flash as well as the PSRAM.
 *
 * To enable the hardware SPI driver, add the following line *before* including
 * FastLED.h:
 *
 * #define FASTLED_ALL_PINS_HARDWARE_SPI
 *
 * This driver uses the VSPI bus by default (GPIO 18, 19, 23, & 5). To use the 
 * HSPI bus (GPIO 14, 12, 13, & 15) add the following line *before* including
 * FastLED.h:
 * 
 * #define FASTLED_ESP32_SPI_BUS HSPI
 * 
 */

// may not be necessary, but FastLED.h kicks off an include to led_sysdefs.h, which checks for ESP32,
// then includes https://github.com/FastLED/FastLED/blob/master/src/led_sysdefs.h#L41
#ifndef ESP32
#define ESP32
#endif

#define FASTLED_ALL_PINS_HARDWARE_SPI // <-- must be defined BEFORE FastLED.h included
#define FASTLED_ESP32_SPI_BUS VSPI
#include <FastLED.h>
CRGB leds[NUMPIXELS];


//////////////////////////////////////////////////////////////////////////////////////////
// init radio
/* https://github.com/dparson55/NRFLite/blob/4e425d742ca8879d654a270c7c02c13440476e7a/examples/Basic_RX_ESP32/Basic_RX_ESP32.ino
 * 
 * Demonstrates simple RX operation with an ESP32.
 * Any of the Basic_TX examples can be used as a transmitter.
 * 
 * ESP's require the use of '__attribute__((packed))' on the RadioPacket data structure
 * to ensure the bytes within the structure are aligned properly in memory.
 * 
 * The ESP32 SPI library supports configurable SPI pins and NRFLite's mechanism to support this is shown.
*/

struct __attribute__((packed)) RadioPacket  // Any packet up to 32 bytes can be sent.
{                                            //  index[width]:bytes so far - 256 bits max packet size
  uint8_t  SHARED_SECRET;                    //  0[8]:1
  uint8_t  senderId;                         //  8[8]:1
  uint32_t encoderPosition;                  //  16[32]:4
  uint8_t  animationId;                      //  48[8]:1
  // uint32_t keyframe;                      //  56[?]:1-25
                                             // 255[0]:0
};


NRFLite _radio;
RadioPacket _radioData;

// ezscb.com esp32 feather ~v1 SPI2/HSPI 
const static uint8_t PIN_RADIO_CE = 27;
const static uint8_t PIN_RADIO_CSN = 15;
const static uint8_t PIN_RADIO_MOSI = 13;
const static uint8_t PIN_RADIO_MISO = 12;
const static uint8_t PIN_RADIO_SCK = 14;
// PIN_RADIO_IRQ = 33
const static uint8_t RADIO_ID = (uint8_t)random();
const static uint8_t SHARED_RADIO_ID = 1; // from after litewarm master 3ea81e3f4b1211809066e6f9649927cf23428956
const static uint8_t SHARED_SECRET = 42;  // bikelight scarves use this & radio_id = 1



#include "animations/ColorChooser.h"
#include "animations/Crossfade.h"
#include "animations/DiamondNecklace.h"
#include "animations/Dimmer.h"
#include "animations/FuckMyEyes.h"
#include "animations/Race.h"
#include "animations/Rainbow.h"
#include "animations/Stars.h"
#include "animations/Stripes.h"

// Load animations...
Crossfade crossfade(knob, leds);
ColorChooser color_chooser(knob, leds);
Race race(knob, leds);
Stars stars(knob, leds);
Rainbow rainbow(knob, leds);
FuckMyEyes fuck_my_eyes(knob, leds);
Stripes stripes(knob, leds);
DiamondNecklace diamond_necklace(knob, leds);
Dimmer dimmer(knob, leds);

Animation *current_animation = &diamond_necklace;

int animation_index = 0;
int previous_animation_index = -1;
void playAnimation(){
  if (animation_index != previous_animation_index) {
    if (animation_index > 8) animation_index = 0;
    // BUG CAUTION
    // never follow one animation function immediately with itself in the the
    // next case
    switch (animation_index) {
      case 0:
        current_animation = &crossfade;
        break;
      case 1:
        current_animation = &color_chooser;
        break;
      case 2:
        current_animation = &race;
        break;
      case 3:
        current_animation = &stars;
        // current_animation = &stripes;
        break;
      case 4:
        current_animation = &rainbow;
        break;
      case 5:
        current_animation = &fuck_my_eyes;
        break;
      case 6:
        // TODO figure out why Stripes causes kernel panic
        // current_animation = &stripes;
        // temporary reuse other animation
        current_animation = &stars;
        break;
      case 7:
        current_animation = &diamond_necklace;
        break;
      case 8:
        current_animation = &dimmer;
        break;
      default:
        // Serial.println("\n\nWARN: default animation switch case");
        break;
    }
    current_animation->setup();
    previous_animation_index = animation_index;
    _radioData.animationId = animation_index;
  }
  current_animation->run();
  FastLED.show();
}



///////////////////////////////////////////////////////////////////////////////////////////
// init rotary encoder
// ESP32Encoder encoder;
// uint32_t encoderPosition = 0;

// Bounce2::Button button_debouncer = Bounce2::Button();



///////////////////////////////////////////////////////////////////////////////////////////
// setup
void setup() {
    // Initialize serial communication at 115200 bits per second:
    Serial.begin(115200);


    // FastLED
    // https://github.com/FastLED/FastLED/blob/master/src/FastLED.h#L246
    FastLED.addLeds<APA102, LED_spiMosi, LED_spiClk, BGR>(leds, NUMPIXELS);  // BGR ordering is typical
    // FastLED.setBrightness(84);
    Serial.println("main.setup(): FastLED.addLeds() complete\n");
    fill_solid(leds, NUMPIXELS, CRGB::Green);
    // fill_solid(leds, NUMPIXELS, CRGB::Blue);
    FastLED.show();
    delay(1000);



    // nrf24 radio 
    // https://nrf24.github.io/RF24/index.html#autotoc_md45
    SPI.begin(PIN_RADIO_SCK, PIN_RADIO_MISO, PIN_RADIO_MOSI, PIN_RADIO_CSN);
    // Indicate to NRFLite that it should not call SPI.begin() during initialization since it has already been done.
    uint8_t callSpiBegin = 0;
    // init radio w common ID so all are in "broadcast" mode
    // TODO NRFLite::BITRATE250KBPS compat w/ bikelites, any improvements?
    if (!_radio.init(SHARED_RADIO_ID, PIN_RADIO_CE, PIN_RADIO_CSN, NRFLite::BITRATE2MBPS, 100, callSpiBegin))
    {
        Serial.println("Cannot communicate with radio");
        // while (1); // Wait here forever.
    }
    Serial.println("main.setup(): _radio.init() complete");
    _radioData.senderId = RADIO_ID;
    _radioData.encoderPosition = 255; // 255 for now to indicate init but invalid
    _radioData.animationId = 255;     // 255 for now to indicate init but invalid
    

    // CALL MyKnob.Setup()
    knob.setup();

    // Rotary Encoder Knob
    // https://github.com/madhephaestus/ESP32Encoder/blob/master/examples/Encoder/Encoder.ino
    // ESP32Encoder::useInternalWeakPullResistors=UP;
    // // use pin 19 and 18 for the first encoder
    // encoder.attachHalfQuad(17, 16);
    // // clear the encoder's raw count and set the tracked count to zero
    // encoder.clearCount();
    // Serial.println("Encoder Start = " + String((int32_t)encoder.getCount()));


    // button_debouncer.attach(buttonPin, INPUT_PULLUP);
    // button_debouncer.interval(25);



    Serial.printf("finished setup\n");
    // Now the task scheduler, which takes over control of scheduling individual tasks, is automatically started.
}



///////////////////////////////////////////////////////////////////////////////////////////
// main loop
// TODO refactor loop() so millis() inner-loop state not needed - ugly
uint32_t now = 0;
bool localUpdate = false;
bool remoteUpdate = false;

void loop() {
  // tracking updates in superloop (not concurrent friendly!!!)
  playAnimation();
  localUpdate = false;

  // can set localUpdate true
  knob.check(&animation_index, &localUpdate);

  // (millis() will always not always be called w/ sub-ms frequency)
  now = millis();


  // enter SEND mode AT MOST every ~5 sec or so (currently 5 sec heartbeat)
  if (now % 5000 == 0 || localUpdate)
  {
      _radioData.animationId = animation_index;
      _radioData.encoderPosition = knob.get();
      String msg = "<== SENT [";
      msg += RADIO_ID;
      msg += "=>";
      msg += SHARED_RADIO_ID;
      msg += "]: ";
      msg += _radioData.animationId;
      msg += " -- ";
      msg += _radioData.encoderPosition; 
      Serial.println(msg);

      if (_radio.send(SHARED_RADIO_ID, &_radioData, sizeof(_radioData)), NRFLite::NO_ACK)
      {
          // Serial.println("...Success");
      }
      else
      {
          Serial.println("...Failed");
      }
  }
  // SIDE-EFFECT: hasData() leaves radio in receive mode
  while(_radio.hasData())
  {
      _radio.readData(&_radioData);
      
      String msg = "==> RCVD [";
      msg += _radioData.senderId;
      msg += "=>";
      msg += SHARED_RADIO_ID;
      msg += "]: ";
      msg += _radioData.animationId;
      msg += " -- ";
      msg += _radioData.encoderPosition;

      Serial.println(msg);

      animation_index = _radioData.animationId;
      knob.set(_radioData.encoderPosition);
      Serial.print(knob.get());
      Serial.println(": setting encoderPosition from incoming packet");
  }
  // playAnimation();
}

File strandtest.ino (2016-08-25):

#include "FastLED.h"
#include <Adafruit_DotStar.h>
#include <SPI.h>         // COMMENT OUT THIS LINE FOR GEMMA OR TRINKET
#include <Bounce2.h>
#include <Encoder.h>

#define NUMPIXELS 150
#define DATAPIN    4
#define CLOCKPIN   5

Adafruit_DotStar strip = Adafruit_DotStar(
  NUMPIXELS, DATAPIN, CLOCKPIN, DOTSTAR_BRG);

int buttonPin =  A0;
int rotary1 = 2;
int rotary2 = 3;
long posRotary = -999;
int      head  = 0; // Index of first 'on' and 'off' pixels
const uint32_t white = 0xFFFFFF;
const uint32_t red = 0x00FF00;
const uint32_t green = 0xFF0000;
const uint32_t blue = 0x0000FF;
const uint32_t off = 0x000000;
int animationIndex = 0;

int buttonPressCount = 0;

Bounce button_debouncer = Bounce();
Encoder knob(rotary1, rotary2);
CRGB leds[NUMPIXELS];

void setup() {
	FastLED.addLeds<DOTSTAR, DATAPIN, CLOCKPIN, RGB>(leds, NUMPIXELS);
  strip.begin(); // Initialize pins for output
  strip.show();  // Turn all LEDs off ASAP
  Serial.begin(57600);
  
  pinMode(buttonPin, INPUT_PULLUP);
  button_debouncer.attach(buttonPin);
  button_debouncer.interval(5);

  pinMode(rotary1, INPUT_PULLUP);
  pinMode(rotary2, INPUT_PULLUP);
}

void loop() {
  button_debouncer.update();
  playAnimation();
  checkRotary(millis());
  checkButton();
}

void playAnimation(){
  if (animationIndex > 6) animationIndex = 0;
  switch (animationIndex) {
    case 0:
      shimmer();
      break;
    case 1:
      strobe();
      break;
    case 2:
      dazzle();
      break;
    case 3:
      find_my_bike();
      break;
		case 4:
			crossfade();
			break;
    case 5:
      race();
      break;
		case 6:
			color_slide();
			break;
  }
}

void checkRotary(int loopTime){
  long newPos = knob.read();
  if(newPos != posRotary){
   posRotary = newPos;
   /* Serial.println(newPos); */
  }
}

long lastPressTime = 0;

int checkButton(){
  int buttonState = button_debouncer.read();
  long currentPressTime = millis();
  long difference = currentPressTime - lastPressTime;
  if((buttonState == 0) && (difference > 400)){
    buttonPressCount++;
    /* Serial.print("Button press count: "); */
    /* Serial.println(buttonPressCount); */
		/* Serial.println("BUTTON PRESSED CALLING SWITCH"); */
    /* Serial.println(lastPressTime); */
    /* Serial.println(currentPressTime); */
    lastPressTime = millis();
    animationIndex++;
  }
}

void strand_off(){
  complete_color(off);
}

void crossfade(){
	int dlay = confineRotary(1, 500);
  static uint8_t hue = 0;
  if(nonBlockDelay(dlay)) {
    FastLED.showColor(CHSV(hue++, 255, 255)); 
  }
}

int r_head = 0;
int g_head = 0;
int b_head = 0;

void shimmer(){
  int dlay = confineRotary(5, 500);
  if(nonBlockDelay(dlay)) {
    complete_color(off); 
    r_head++;
    if(r_head > NUMPIXELS) r_head = 0;
    // green, red, blue 
    draw_snake(r_head, 30, 255, 100);

    b_head++;
    if(b_head > NUMPIXELS) b_head = 0;
    draw_snake((NUMPIXELS - b_head), 30, 0, 255);

    g_head = g_head + 2;
    if(g_head > NUMPIXELS) g_head = 0;
    draw_snake((NUMPIXELS - g_head), 255, 130, 0);

    strip.show();
  }
}

void draw_snake(int head, int green, int red, int blue) {
  int head_minus_5  = remapInRange(head - 5);
  int head_minus_4  = remapInRange(head - 4);
  int head_minus_3  = remapInRange(head - 3);
  int head_minus_2  = remapInRange(head - 2);
  int head_minus_1  = remapInRange(head - 1);
  uint32_t myColor = strip.getPixelColor(head_minus_5);
  Serial.println(String(myColor));
  strip.setPixelColor(head_minus_5, green, red, max((blue - 255), 0));
  strip.setPixelColor(head_minus_4, green, red, max((blue - 100), 0));
  strip.setPixelColor(head_minus_3, green, red, max((blue - 50), 0));
  strip.setPixelColor(head_minus_2, green, red, max((blue - 20), 0));
  strip.setPixelColor(head_minus_1, green, red, blue);
}



void find_my_bike(){
  complete_color(off);
  if(nonBlockDelay(3000)) {
    complete_color(white);
    delay(20);
  }
}

void color_slide(){
	int dlay = confineRotary(5, 500);
  if(nonBlockDelay(dlay)) {
    static uint8_t hue = 0;
    head++;
    head = remapInRange(head);
    leds[head] = CHSV(hue++, 255, 255);
    FastLED.show();
  }
}

void race(){
 	int dlay = confineRotary(5, 500);
  if(nonBlockDelay(dlay)) {
    static uint8_t hue = 0;
    leds[head - 1] = CRGB::Black;
    leds[head] = CHSV(hue++, 255, 150);
    head++;
    leds[head] = CHSV(hue++, 255, 255);
    if(head > NUMPIXELS) head = 0;
    head = remapInRange(head);
    leds[head] = CHSV(hue++, 255, 255);
    FastLED.show();
  }
}

uint32_t lastColor = red;
uint32_t currentColor = red;
void dazzle(){
  int dlay = confineRotary(0, 500);
  if(nonBlockDelay(dlay)) { 
    switch (lastColor) {
      case red:
        complete_color(green);
        lastColor = green;
        break;
      case green:
        complete_color(blue);
        lastColor = blue;
        break;
      case blue:
        complete_color(red);
        lastColor = red;
        break;
    }
  }
}

uint32_t lastStrobeColor = white;
void strobe(){
  int dlay = confineRotary(0, 1000);
  if(nonBlockDelay(dlay)) { 
    switch (lastStrobeColor) {
      case off:
        complete_color(white);
        lastStrobeColor = white;
        break;
      case white:
        complete_color(off);
        lastStrobeColor = off;
        break;
    }
  }
}

void complete_color(uint32_t color){
  for (int leds = 0 ; leds < NUMPIXELS; leds++){
    strip.setPixelColor(leds, color);
  }
  strip.show();
}

int confineRotary(int start, int finish) {
  if(posRotary < start) { 
    posRotary = start;
    knob.write(start);
  }
  if(posRotary > finish) {
    posRotary = finish;
    knob.write(finish);
  }
  return posRotary;
}

int remapInRange(int index){
  if (index < 0) index = (NUMPIXELS - 1) + index;
  if (index > NUMPIXELS) index = 0;
  return index;
}

long previousMillis = 0;
bool nonBlockDelay(int interval){
  unsigned long currentMillis = millis();
  if(currentMillis - previousMillis > interval) {
    previousMillis = currentMillis;   
    return true;
  }
  return false;
}

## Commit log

2019-06-07 a slightly buggy branch
    [main.cpp]
2019-06-07 some kinda fix, whew, we tired
    [main.cpp]
2019-06-07 Things are working as of now.
    - Removed Serial comments
    - Race now does what color slide once did
    - Color slide is no longer included as it was buggy
    - No plans to reimplement race as it was originally, never really liked
    it all that much.
    [main.cpp]
2019-06-08 Add list of materials
2019-06-08 color chooser doesn't quite work for some reason
    [main.cpp]
2019-06-08 It's in working order, but no color chooser
    Interestingly there are problems if i change the order of the case
    statement, I have no idea why.
    [main.cpp]
2019-06-16 Added looping ability.
    This is mostly for color chooser, which still causes some kind of other
    crash. Still working that out, if you want to try it out feel free to
    comment out the switch statment and just run the color chooser
    animation.
    [main.cpp]
2019-06-17 slightly faster defualt intervals for a couple of animations
2019-06-22 very literal move of code not working yet
    [main.cpp]
2019-07-08 Fixes for jittery changes when using rotary
    Previously all parties tried to broadcast constantly, this could turn
    into a feedback loop. Here we prevent the broadcast of a packet unless
    there is a manual change that needs broadcasting.
    Also add a sync period.
2019-07-26 add initial schematic
    [schematic-bu.sch, schematic.brd, schematic.sch]
2019-07-26 try trimming off th external componetns, first board layout
    [schematic.sch]
2019-07-27 add auto routing with pads on back
    [schematic.brd]
2019-07-28 swapped out arduino lib, still have errors
    [schematic.brd, schematic.sch]
2019-07-30 v1 of boards
    [schematic.brd, schematic.sch]
2019-07-30 add a little more beef to some of the power lines
    [schematic.brd]
2019-07-30 v1.1 Fatten some of the leads
    [schematic.brd]
2019-07-31 silk screen change
    [schematic.brd, schematic.sch]
2019-08-02 reorder radio contacts so that they are easy to solder
    [schematic.brd, schematic.sch]
2019-08-02 tidy schematic slightly
    [schematic.sch]
2019-08-02 remove old backup
    [schematic-bu.sch]
2019-08-06 update for PCB use
2019-08-06 rearrange JST connection for strip, bump version
    [schematic.brd, schematic.sch]
2019-08-07 reorder animations and tighten rainbow
    [main.cpp]
2019-08-07 hold actions are now printed to serial
2019-08-08 a couple more animations
2019-08-14 comboPattern string -> switch case dispatcher works
2019-08-14 FIX swapped pin bug CS<->CSM v1.3; SK9822 BGR order
    [main.cpp]
2019-08-14 cmdMode starts after med->short combo
    [main.cpp]
2019-08-22 change strip to WS and flip data and clock
    [main.cpp]
2019-08-22 printf.h printf() -> serial helper lib
2019-08-23 cap brightness of dimmer to prevent 1A power source failure
2019-10-19 🐛 Fix config issue
    This issue seems to be caused by comments after the values. This used to
    work, but after a PIO update, no longer does.
2019-10-25 🌈 logo for readme
2019-12-13 update readme, teensy debug journal, teensy pio env
2023-09-09 Update README.md
    add commit links to readme to help find teensy-compatible master commits

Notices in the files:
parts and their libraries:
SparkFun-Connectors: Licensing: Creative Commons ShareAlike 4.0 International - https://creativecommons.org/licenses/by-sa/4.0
